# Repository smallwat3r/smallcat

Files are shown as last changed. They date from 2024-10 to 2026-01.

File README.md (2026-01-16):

# Smallcat

A diodeless 26-key keyboard, featuring the purr-fect code reviewer, my cat, Lila.

This repo contains Gerber files, KiCad files, my keymap, and links to QMK and Vial-QMK firmware for the Smallcat.

## Versions

There are two versions of the Smallcat: **split** and **unibody**.

Both versions share the same column splay:

| Finger | Splay |
|---|---|
| Pinkie | 10° |
| Ring | 5° |
| Middle | 2° |

### Split

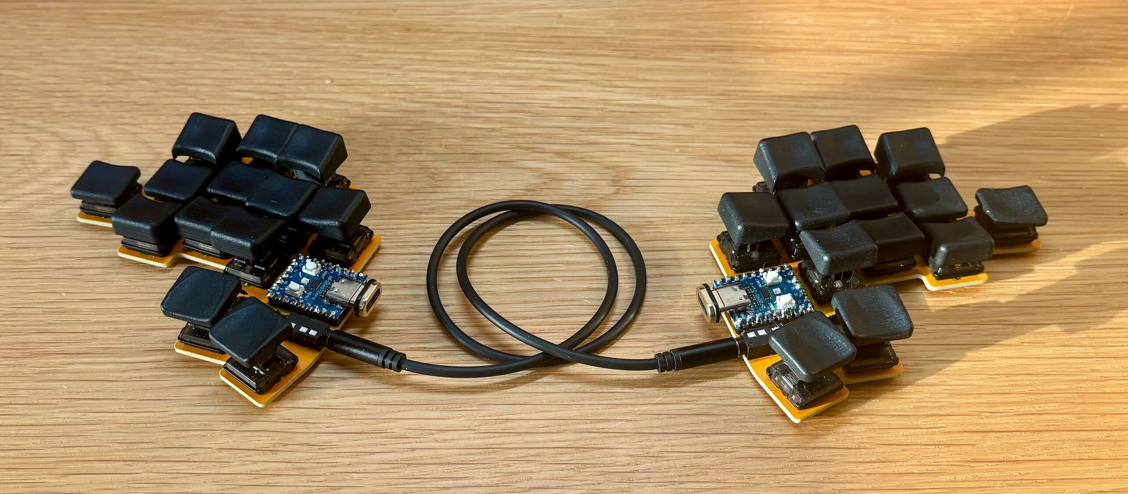
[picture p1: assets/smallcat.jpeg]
smallcat


| Component | Specification |
|---|---|
| Controller | 2x RP2040-Zero footprint ([example](https://www.waveshare.com/wiki/RP2040-Zero)) |
| Switches | 26 low profile Choc (soldered) |
| Diodes | None required |
| Connection | TRRS jack |

### Unibody

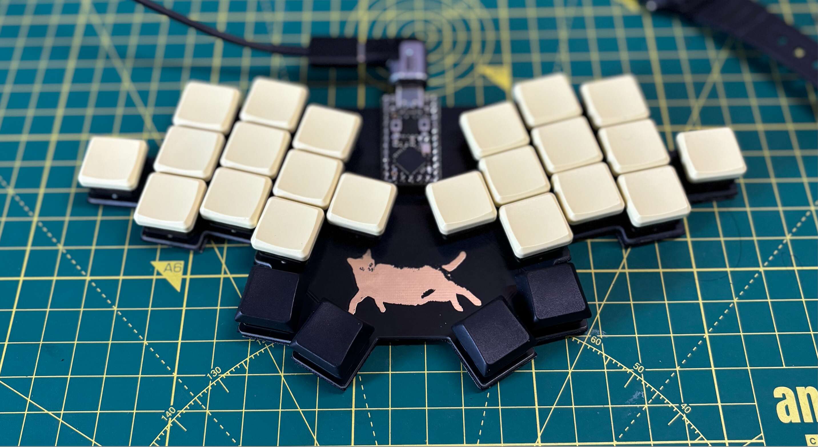
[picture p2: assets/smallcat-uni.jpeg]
smallcat


| Component | Specification |
|---|---|
| Controller | 1x RP2040 Pro Micro with 28 I/O pins ([example](https://www.aliexpress.com/i/1005006097129434.html)) |
| Switches | 26 low profile Choc (soldered) |
| Diodes | None required |

#### Build notes

The unibody version has a few unconventional details:

- **Pro Micro model**: Use a Pro Micro with extra pins (18 and 24) near the middle of the board.

- **Pin clearance**: The space between pins 18 and 24 is narrow. You may need to trim the plastic between them, just ensure enough remains so the metal contacts don't touch. [See photo](./assets/pins_uni.jpeg). This is a simple workaround to use the extra pins and keep the board diodeless.

- **Pin headers**: PCB holes are narrower than standard. Use machined conical pin headers like [these](https://www.proto-advantage.com/store/datasheets/MPH100IMP40M-G-V-TH.pdf).

- **Controller orientation**: Install component-side up (not face-down like most keyboards). This way the boot and reset buttons are accessible.

## Case

Simple press-fit cases with no screws or hardware. The base is 1mm larger than the PCB, allowing it to slide in snugly. You may need to trim some edges slightly to ensure a tight fit. Small bumpons under the PCB prevent the pins from resting directly on the case.

| Split | Uni |
|---|-----|
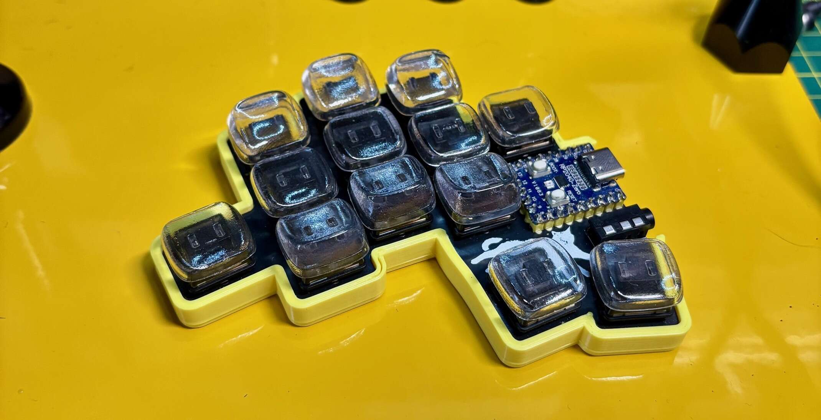
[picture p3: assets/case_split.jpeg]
case_split
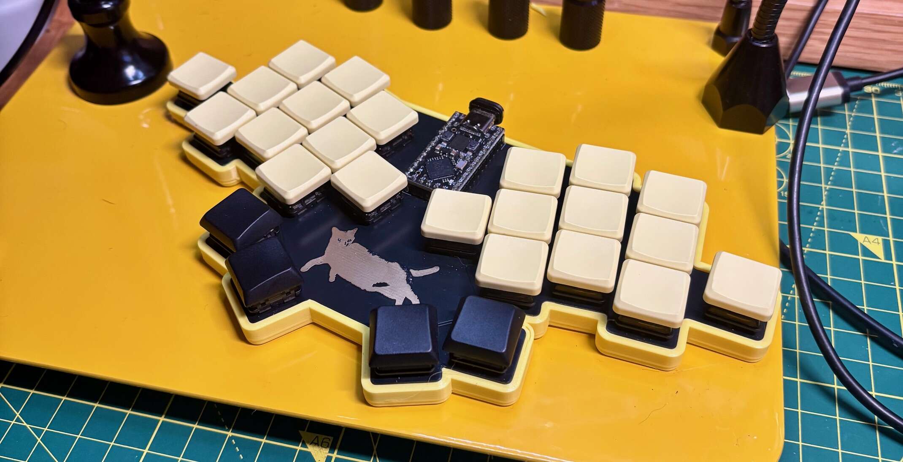
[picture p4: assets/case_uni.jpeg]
case_uni
|  |  |

## Firmware

I maintain my own [QMK keymap](https://github.com/smallwat3r/qmk-keymap), which includes my keymap, configuration for the Smallcat, and a ready-to-flash UF2 file.

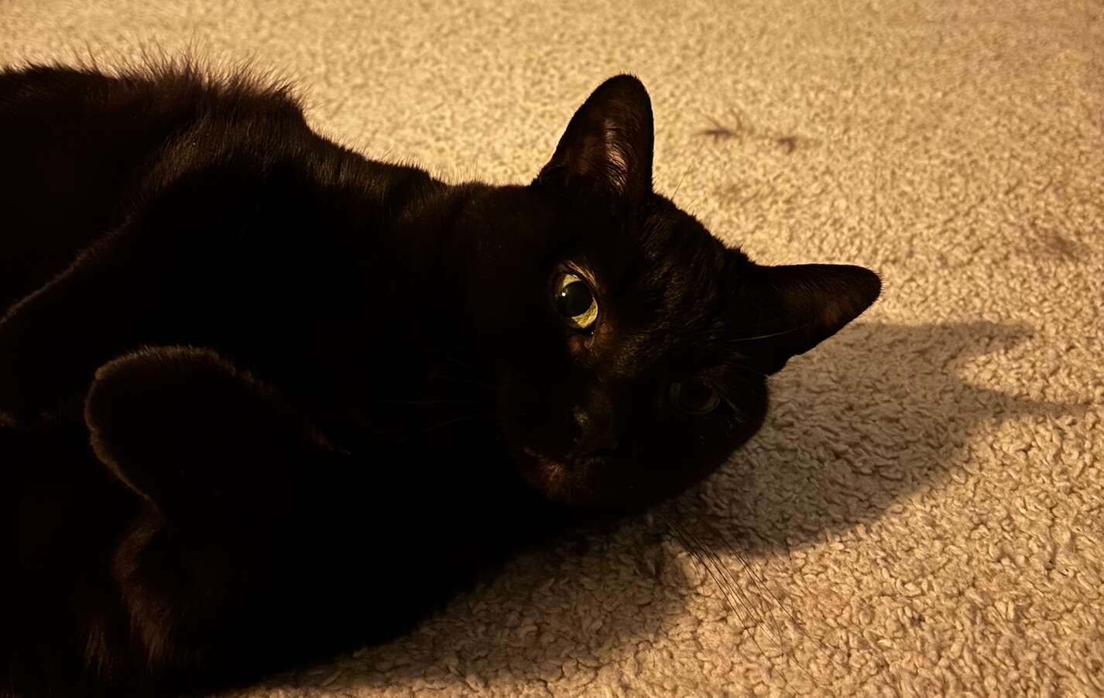
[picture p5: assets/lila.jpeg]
lila


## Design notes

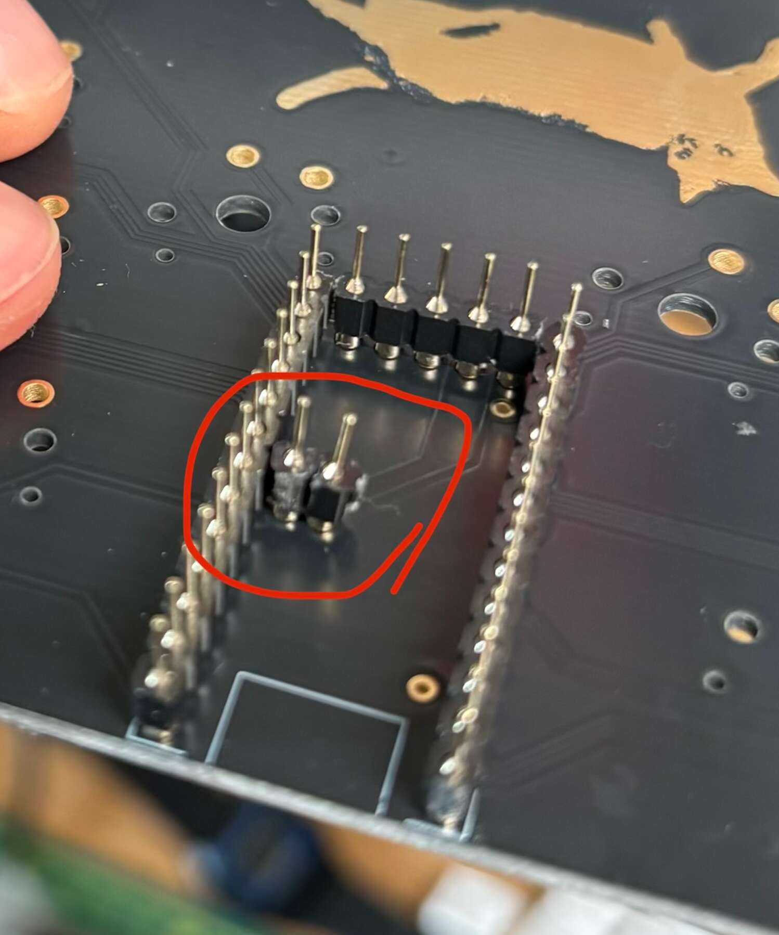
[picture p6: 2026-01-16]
assets/pins_uni.jpeg

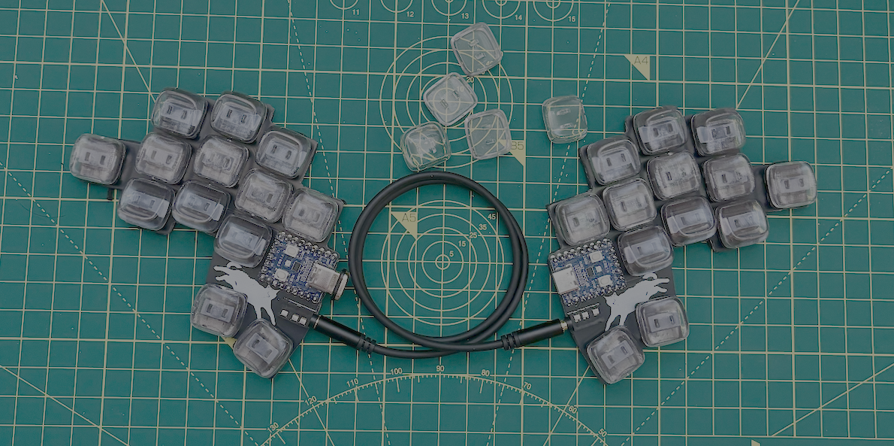
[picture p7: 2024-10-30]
images/smallcat.png

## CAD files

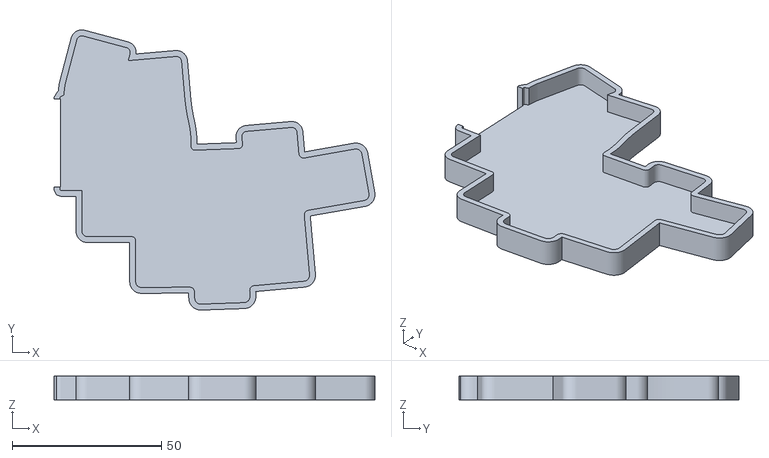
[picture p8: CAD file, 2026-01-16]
case/v1.0/split/left.stl
107.6 x 93.9 x 8.00

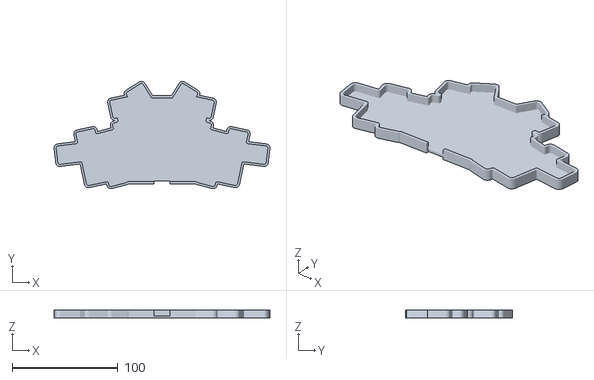
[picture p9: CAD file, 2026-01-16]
case/v1.0/uni/case.stl
204.1 x 101.5 x 8.00

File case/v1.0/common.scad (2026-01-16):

// Smallcat Keyboard Case - Common Parameters and Modules
// Shared code for all case variants

// Parameters
wall_thickness = 2;        // Wall thickness in mm
case_depth = 8;            // Total case depth in mm
pcb_thickness = 1.6;       // PCB thickness in mm
pcb_clearance = 0.2;       // Clearance around PCB in mm
bottom_thickness = 2;      // Bottom plate thickness in mm

// Main case module - takes PCB outline, cutout passed as children()
module case_bottom(pcb_outline) {
    difference() {
        // Outer shell
        linear_extrude(height=case_depth)
            offset(r=wall_thickness + pcb_clearance)
                polygon(pcb_outline);

        // Inner cavity for PCB
        translate([0, 0, bottom_thickness])
            linear_extrude(height=case_depth)
                offset(r=pcb_clearance)
                    polygon(pcb_outline);

        // Cutout geometry passed as children
        children();
    }
}

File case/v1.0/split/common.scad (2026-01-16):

// Smallcat Split Keyboard Case - Common Parameters and Modules
// Shared code for split case variants

include <../common.scad>

// Connector edge cutout parameters
connector_cutout_start = 39;   // Y start position
connector_cutout_end = 68.5;   // Y end position

// PCB dimensions
pcb_max_x = 103.216;

// Mirror points across X axis
function mirror_x(points, max_x) = [for (p = points) [max_x - p[0], p[1]]];

// Left half PCB outline (right half is mirrored from this)
left_pcb_outline = [
    [103.194, 36.855],
    [103.216, 36.386],
    [103.119, 35.926],
    [102.910, 35.506],
    [102.602, 35.152],
    [102.214, 34.888],
    [101.772, 34.729],
    [83.084, 31.474],
    [82.630, 31.365],
    [82.219, 31.142],
    [81.882, 30.819],
    [81.640, 30.420],
    [81.510, 29.971],
    [81.501, 29.504],
    [83.276, 9.574],
    [83.243, 9.102],
    [83.088, 8.655],
    [82.821, 8.264],
    [82.461, 7.957],
    [82.033, 7.755],
    [81.567, 7.673],
    [64.800, 6.172],
    [64.365, 6.070],
    [63.969, 5.862],
    [63.638, 5.561],
    [63.393, 5.187],
    [63.250, 4.763],
    [63.217, 4.317],
    [63.292, 2.398],
    [63.257, 1.916],
    [63.094, 1.461],
    [62.814, 1.067],
    [62.439, 0.763],
    [61.996, 0.571],
    [61.517, 0.505],
    [47.048, 0.000],
    [46.564, 0.041],
    [46.109, 0.211],
    [45.717, 0.498],
    [45.418, 0.881],
    [45.233, 1.330],
    [45.177, 1.813],
    [45.127, 3.848],
    [45.074, 4.318],
    [44.901, 4.757],
    [44.618, 5.136],
    [44.246, 5.427],
    [43.810, 5.610],
    [43.342, 5.673],
    [26.900, 5.617],
    [26.501, 5.680],
    [26.132, 5.844],
    [25.817, 6.098],
    [25.578, 6.424],
    [25.432, 6.801],
    [25.388, 7.203],
    [25.379, 21.037],
    [25.335, 21.439],
    [25.188, 21.816],
    [24.950, 22.142],
    [24.635, 22.395],
    [24.266, 22.560],
    [23.867, 22.623],
    [8.900, 22.642],
    [8.501, 22.705],
    [8.132, 22.869],
    [7.817, 23.123],
    [7.578, 23.449],
    [7.432, 23.826],
    [7.388, 24.228],
    [7.396, 38.144],
    [0.000, 38.144],
    [0.000, 69.058],
    [1.321, 69.810],
    [1.376, 70.561],
    [1.446, 71.310],
    [1.532, 72.058],
    [1.633, 72.804],
    [1.750, 73.548],
    [5.652, 88.368],
    [5.794, 88.749],
    [6.034, 89.078],
    [6.354, 89.329],
    [6.731, 89.485],
    [7.135, 89.533],
    [7.537, 89.470],
    [22.037, 85.595],
    [22.405, 85.439],
    [22.719, 85.191],
    [22.957, 84.870],
    [23.102, 84.497],
    [23.145, 84.100],
    [23.081, 83.705],
    [22.431, 81.205],
    [38.727, 82.619],
    [39.126, 82.598],
    [39.506, 82.475],
    [39.842, 82.258],
    [40.110, 81.962],
    [40.293, 81.607],
    [40.379, 81.216],
    [41.391, 69.611],
    [41.513, 68.247],
    [41.667, 66.885],
    [41.852, 65.528],
    [42.070, 64.176],
    [42.318, 62.829],
    [42.598, 61.488],
    [42.828, 60.458],
    [43.028, 59.423],
    [43.198, 58.382],
    [43.339, 57.337],
    [43.449, 56.289],
    [43.529, 55.237],
    [43.535, 52.568],
    [43.630, 52.187],
    [43.819, 51.842],
    [44.088, 51.557],
    [44.421, 51.348],
    [44.795, 51.230],
    [45.187, 51.211],
    [59.855, 51.745],
    [60.236, 51.841],
    [60.581, 52.029],
    [60.867, 52.298],
    [61.076, 52.631],
    [61.194, 53.005],
    [61.213, 53.398],
    [60.992, 55.848],
    [61.011, 56.240],
    [61.129, 56.615],
    [61.338, 56.948],
    [61.624, 57.217],
    [61.969, 57.405],
    [62.350, 57.500],
    [77.434, 58.828],
    [77.821, 58.803],
    [78.190, 58.682],
    [78.517, 58.473],
    [78.781, 58.189],
    [78.966, 57.847],
    [79.059, 57.471],
    [79.692, 50.183],
    [79.800, 49.720],
    [80.025, 49.301],
    [80.352, 48.956],
    [80.759, 48.710],
    [81.216, 48.579],
    [81.692, 48.573],
    [98.697, 51.579],
    [99.166, 51.601],
    [99.626, 51.505],
    [100.046, 51.296],
    [100.400, 50.987],
    [100.664, 50.600],
    [100.823, 50.158]
];

// Connector edge cutout module (clears entire inner edge section for USB + TRRS)
// Removes both wall and base plate so the base stops before the border
module connector_cutout(x_pos) {
    e = 0.01;  // Epsilon to avoid coincident faces
    cutout_length = connector_cutout_end - connector_cutout_start;
    cutout_width = wall_thickness + pcb_clearance + 2.8;
    translate([x_pos, connector_cutout_start - e, -e])
        cube([cutout_width + e, cutout_length + 2*e, case_depth + 2*e]);
}

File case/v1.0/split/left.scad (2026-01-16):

// Smallcat Split Keyboard Case - Left Half
// Tray-style case design

include <common.scad>

case_bottom(left_pcb_outline) {
    connector_cutout(-5);
}

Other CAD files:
case/v1.0/split/right.stl
case/v1.0/split/right.scad
case/v1.0/uni/case.scad

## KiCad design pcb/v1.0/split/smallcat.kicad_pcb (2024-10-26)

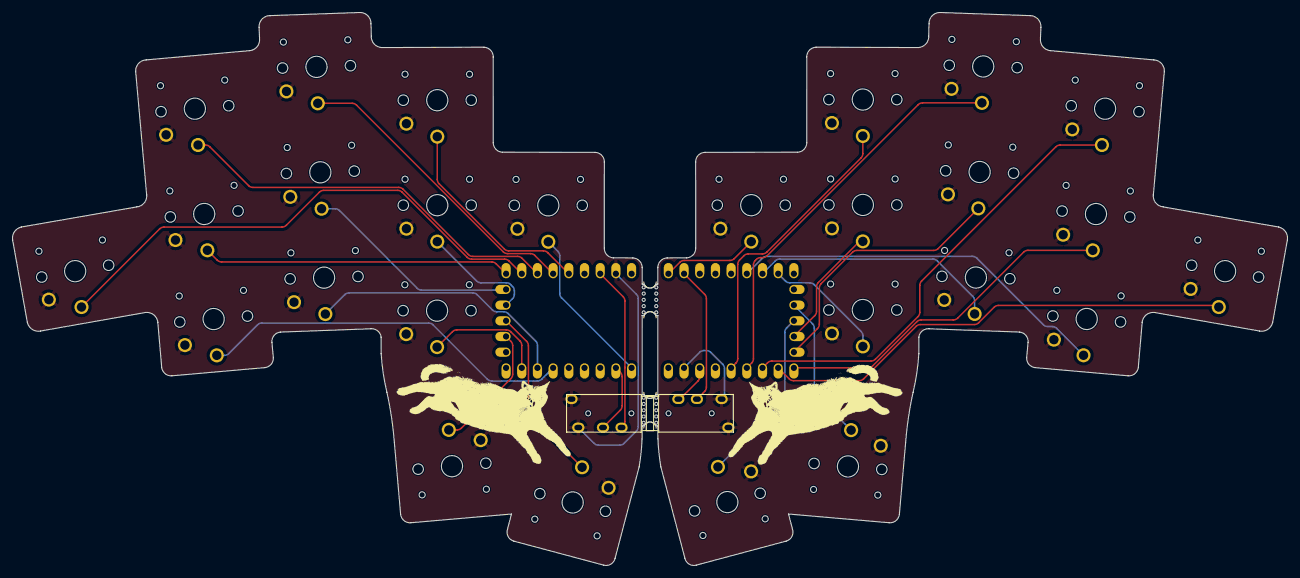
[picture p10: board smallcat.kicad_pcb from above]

Board: 2 copper layers, 206.4 x 89.5 mm, 32 parts (0 on the bottom side), 30 nets.

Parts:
J1, J2: AudioJack4dpb; TRRS-PJ-320A
SW3, SW3_r1, SW4, SW4_r1, SW5, SW5_r1, SW7_r1, SW8, SW8_r1, SW9, SW9_r1, SW10, SW11, SW11_r1, SW11_r1#2, SW12, SW12_r1, SW15, SW15_r1, SW16, SW17, SW18_r1, SW20, SW20_r1, SW21, SW21_r1: SW_Push; choc-v1-with-millmax
U?: rp2040-zero-tht
U?#2: rp2040-zero-tht
mouse-bite-2mm-slot, mouse-bite-2mm-slot#2: VAL**; mouse-bite-5mm-slot-with-space-for-track

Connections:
Switch2: SW3.1, U?#2.17
Switch2_r: SW3_r1.1, U?.17
Switch3: SW4.1, U?#2.18
Switch3_r: SW4_r1.1, U?.18
Switch4: SW5.1, U?#2.19
Switch4_r: SW5_r1.1, U?.19
Switch6: SW8.1, U?#2.16
Switch6_r: SW7_r1.1, U?.16
Switch7: SW9.1, U?#2.15
Switch7_r: SW8_r1.1, U?.15
Switch8: SW10.1, U?#2.14
Switch8_r: SW9_r1.1, U?.14
Switch9: SW11.1, U?#2.13
Switch9_r: SW11_r1.1, U?.13
Switch10: SW12.1, U?#2.1
Switch10_r: SW12_r1.1, U?.1
Switch12: SW15.1, U?#2.6
Switch12_r: SW18_r1.1, U?.6
Switch13: SW16.1, U?#2.7
Switch13_r: SW15_r1.1, U?.7
Switch14: SW17.1, U?#2.8
Switch14_r: SW11_r1#2.1, U?.8
Switch16: SW21.1, U?#2.11
Switch16_r: SW21_r1.1, U?.11
Switch17: SW20.1, U?#2.12
Switch17_r: SW20_r1.1, U?.12
Switch18: J2.R1, U?#2.2
Switch18_r: J1.R1, U?.2
gnd: J1.S, J1.T, J2.S, J2.T, SW3.2, SW3_r1.2, SW4.2, SW4_r1.2, SW5.2, SW5_r1.2, SW7_r1.2, SW8.2, SW8_r1.2, SW9.2, SW9_r1.2, SW10.2, SW11.2, SW11_r1.2, SW11_r1#2.2, SW12.2, SW12_r1.2, SW15.2, SW15_r1.2, SW16.2, SW17.2, SW18_r1.2, SW20.2, SW20_r1.2, SW21.2, SW21_r1.2, U?.22, U?#2.22
vcc: J1.R2, J2.R2, U?.21, U?#2.21

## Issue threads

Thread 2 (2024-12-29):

love your board, small suggestion...

sadekbaroudi, 2024-12-29:
Hey there! I was gifted a smallcat board recently, and I wanted to hand craft my own repo in qmk instead of using vial (I am too OCD to rely on vial :) )

I couldn't find a link to the source for your vial firmware, and ended up finding it here:
https://github.com/vial-kb/vial-qmk/tree/vial/keyboards/smallcat

Would be awesome if you had a link to it directly from your smallcat repo.

That comment aside, lovely work on this. I'm a 36 key user myself, so using this as an opportunity to try to go down to even fewer keys. The keymap overview image is incredibly helpful. Thanks for taking the time to make and share this board!!

I'm the founder of fingerpunch, if you've heard of it. Long time ergo keyboard guy myself.

smallwat3r, 2025-01-02:
@sadekbaroudi awesome to hear the Smallcat is used by other people, and I'm glad you like it!

I've pushed a commit to add a link to the source files in the README, great suggestion.

I'm actually planning to migrate away from Vial to bare QMK, as some features I'm interested in seems to work best in the latter (such as magic key, that unlocks usage similar to how the [magic sturdy](https://github.com/Ikcelaks/keyboard_layouts/blob/main/magic_sturdy/magic_sturdy.md) layout works). But I haven't had time to dig more into it yet.

Also, had a look at Fingerpunch and your keebs, really nice work! Always great to meet other passionate keyboard users :)

smallwat3r, 2025-02-16:
@sadekbaroudi , finally made the switch to QMK and I do not regret it. Here is my [keymap](https://github.com/smallwat3r/qmk-keymap) for the Smallcat in case you're interested!

sadekbaroudi, 2025-02-16:
@smallwat3r - I missed your previous comment on Jan 2nd. Thank you SO much for taking the time to share your qmk keymap / source. I will definitely take advantage of that. I haven't had a chance to get my board going, but this is most definitely an inspiration to do so sooner than later. Cheers!

Closed 2025-01-02.

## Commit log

2024-10-26 Add versioning
    [smallcat.kicad_pcb]
2024-11-04 Add case designs
    [smallcat_case.step, smallcat_case.stl]
2024-11-10 Add fusion case file
    [smallcat_case.f3d]
2025-03-16 Add image of PCB
2025-07-26 Add unibody board
    [smallcat-uni.kicad_pcb]
2025-07-26 Fix file
    [smallcat-uni.kicad_pcb]
2025-08-04 Edit README
    [smallcat-uni.kicad_pcb]
2026-01-16 OpenSCAD cases (#4)
    * Add openscad cases
    * Better structure
    * Move gerber to pcb directly
    * Remove deprecated note
    * Snuggier fit
    * Updates
    * Move images to assets
    * Updates
    * Add case pictures
    * Update README
    * Better image compression
    * Fix
    [case.scad, case.stl, common.scad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]
